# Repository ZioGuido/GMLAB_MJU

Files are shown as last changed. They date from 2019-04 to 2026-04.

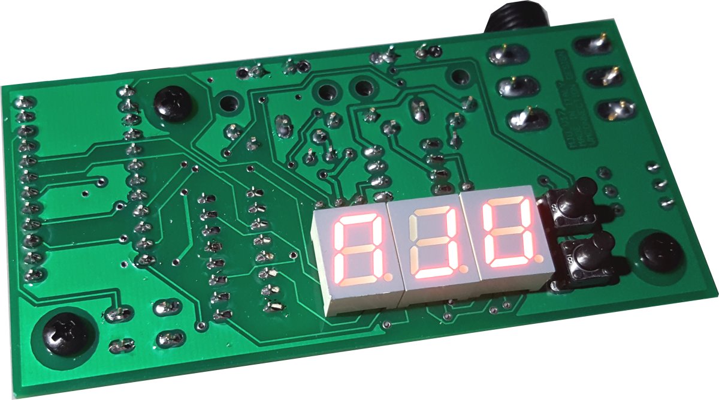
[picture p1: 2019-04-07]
MJU_on.jpg

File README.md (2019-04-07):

# GMLAB_MJU
# MIDI JACK USB

This is an open-source open-hardware D-I-Y Midi event processor and TRS Accessory converter based on Arduino and the Pro-Micro board.
All necessary files are included in this repository. 
Please refer to the included PDF file for details about the assembly and the programming.

Project website: www.gmlab.it

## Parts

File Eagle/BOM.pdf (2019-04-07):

Foglio1

Pagina 1

# MJU

Part | Value | Device | Package | Description
IC1 | | ARDUINO PRO-MICRO
J1 | STEREO JACK | STEREO JACK | STEREO JACK 6.3
LED1 | 7-SEG_SA39-11SRWA | 7-SEG_SA39-11SRWA | SA39-11SRWA | Kingbright 14.2mm (0.56 INCH) SINGLE DIGIT DISPLAY
LED2 | 7-SEG_SA39-11SRWA | 7-SEG_SA39-11SRWA | SA39-11SRWA | Kingbright 14.2mm (0.56 INCH) SINGLE DIGIT DISPLAY
LED3 | 7-SEG_SA39-11SRWA | 7-SEG_SA39-11SRWA | SA39-11SRWA | Kingbright 14.2mm (0.56 INCH) SINGLE DIGIT DISPLAY
MIDI_IN | MAB5SH | MAB5SH | MAB5SH | Female DIN CONNECTOR
MIDI_OUT | MAB5SH | MAB5SH | MAB5SH | Female DIN CONNECTOR
OK1 | 6N137 | 6N137 | DIL08 | MOTOROLA OPTO COUPLER
R1 | 220 | R-EU_0207/7 | 0207/7 | RESISTOR, European symbol
R2 | 100 | R-EU_0207/7 | 0207/7 | RESISTOR, European symbol
R3 | 220 | R-EU_0207/7 | 0207/7 | RESISTOR, European symbol
R4 | 220 | R-EU_0207/7 | 0207/7 | RESISTOR, European symbol
R5 | 100 | R-EU_0207/7 | 0207/7 | RESISTOR, European symbol
R9 | 10K | R-EU_0207/7 | 0207/7 | RESISTOR, European symbol
R10 | 100 | R-EU_0207/7 | 0207/7 | RESISTOR, European symbol
RN1 | 220 | E4R | SIL8 | SIL RESISTOR
RN2 | 220 | E4R | SIL8 | SIL RESISTOR
S1 | b3f-1000 | 10-XX | B3F-10XX | OMRON SWITCH
S2 | b3f-1070 | 10-XX | B3F-10XX | OMRON SWITCH
S3 | b3f-1070 | 10-XX | B3F-10XX | OMRON SWITCH

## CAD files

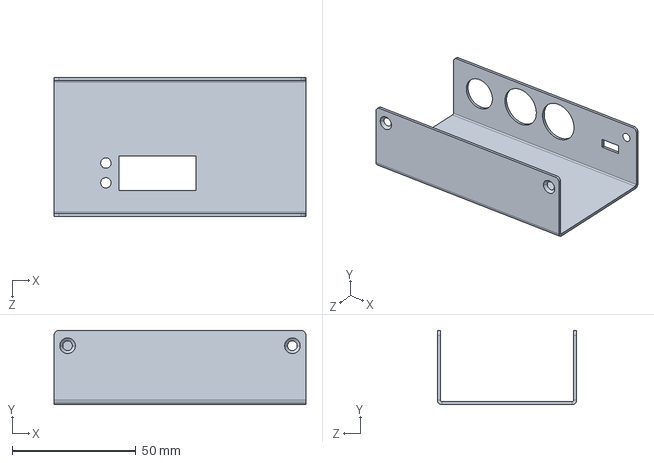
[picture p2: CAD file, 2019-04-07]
3D/Bottom.STEP
102.0 x 30.0 x 56.4 mm

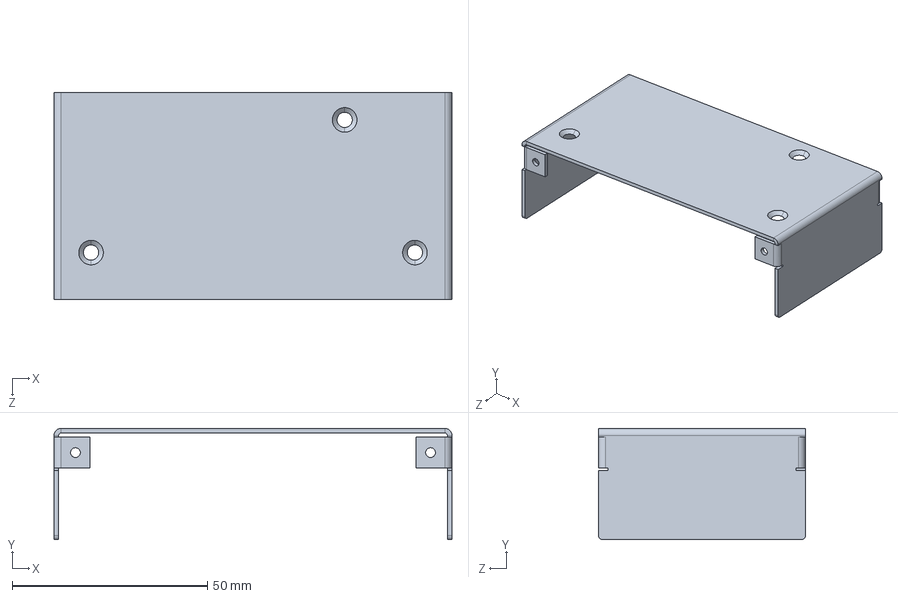
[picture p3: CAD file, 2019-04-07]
3D/Top.STEP
102.0 x 28.5 x 53.0 mm

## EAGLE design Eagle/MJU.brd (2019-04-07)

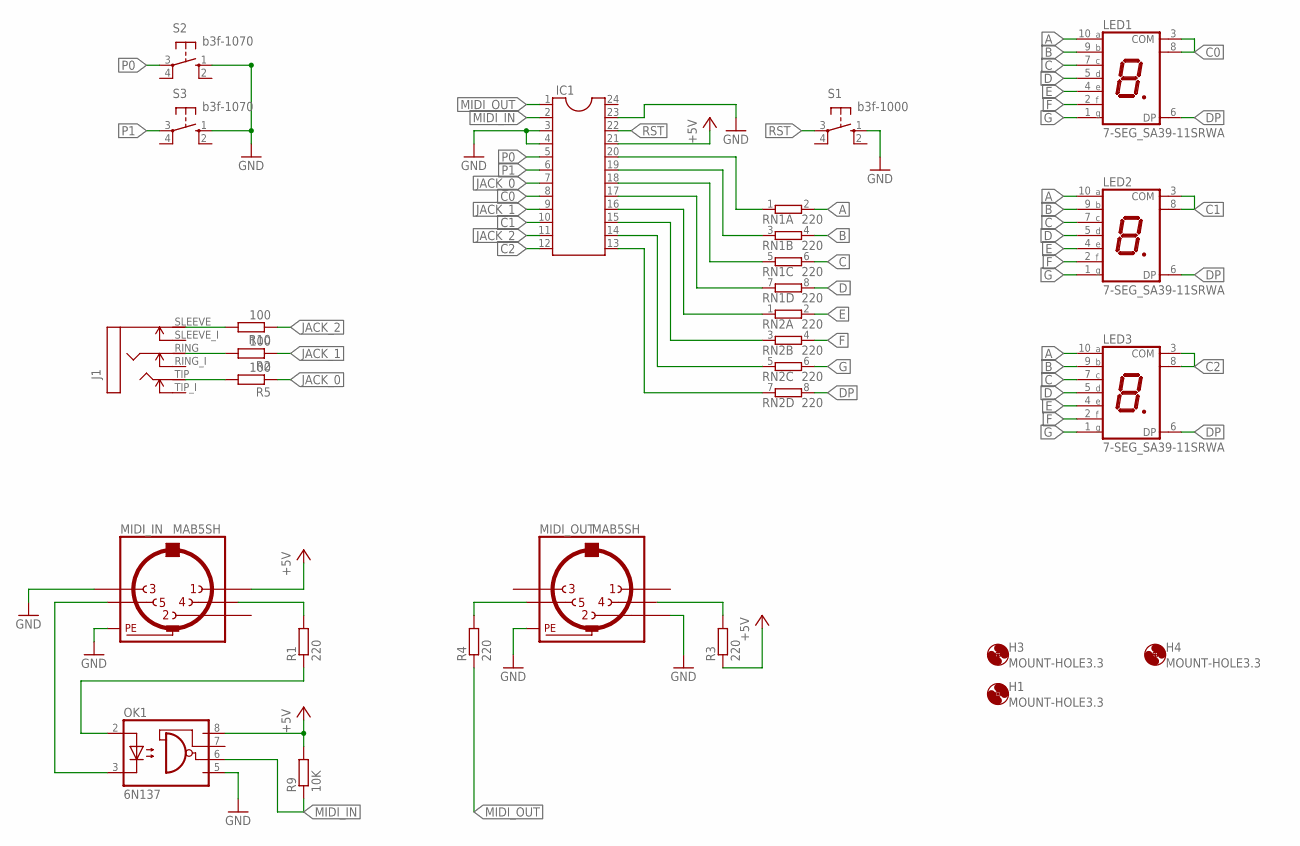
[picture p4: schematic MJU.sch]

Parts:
H1, H3, H4: MOUNT-HOLE3.3; 3,3
IC1: DIL24-6
J1: STEREOSWJACK_ST_TRS_INT; ST_JACK_TRS_INT
LED1, LED2, LED3: 7-SEG_SA39-11SRWA; SA39-11SRWA
MIDI_IN: MAB5SH
MIDI_OUT: MAB5SH
OK1: 6N137; DIL08
R1, R3, R4: 220; 0207/7
R2, R5, R10: 100; 0207/7
R9: 10K; 0207/7
RN1, RN2: 220; SIL8
S1: b3f-1000; B3F-10XX
S2, S3: b3f-1070; B3F-10XX

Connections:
+5V: IC1.21, MIDI_IN.1, OK1.8 (VCC), R3.1, R9.2
A: LED1.10 (A), LED2.10 (A), LED3.10 (A), RN1.2
B: LED1.9 (B), LED2.9 (B), LED3.9 (B), RN1.4 (2)
C: LED1.7 (C), LED2.7 (C), LED3.7 (C), RN1.6 (2)
C0: IC1.8, LED1.3 (COM), LED1.8 (COM)
C1: IC1.10, LED2.3 (COM), LED2.8 (COM)
C2: IC1.12, LED3.3 (COM), LED3.8 (COM)
D: LED1.5 (D), LED2.5 (D), LED3.5 (D), RN1.8 (2)
DP: LED1.6 (DP), LED2.6 (DP), LED3.6 (DP), RN2.8 (2)
E: LED1.4 (E), LED2.4 (E), LED3.4 (E), RN2.2
F: LED1.2 (F), LED2.2 (F), LED3.2 (F), RN2.4 (2)
G: LED1.1 (G), LED2.1 (G), LED3.1 (G), RN2.6 (2)
GND: IC1.3, IC1.4, IC1.23, MIDI_IN.3, MIDI_IN.PE, MIDI_IN.PE@ (PE), MIDI_OUT.2, MIDI_OUT.PE, MIDI_OUT.PE@ (PE), OK1.5 (GND), S1.1 (S), S2.1 (S), S3.1 (S)
JACK_0: IC1.7, R5.1
JACK_1: IC1.9, R2.1
JACK_2: IC1.11, R10.1
MIDI_IN: IC1.2, OK1.6 (VO), R9.1
MIDI_OUT: IC1.1, R4.1
unnamed: J1.SLEEVE (S), R10.2
unnamed: J1.RING (R), R2.2
unnamed: J1.TIP (T), R5.2
unnamed: MIDI_IN.5, OK1.3 (C)
unnamed: OK1.2 (A), R1.1
unnamed: MIDI_IN.4, R1.2
unnamed: MIDI_OUT.5, R4.2
unnamed: MIDI_OUT.4, R3.2
P0: IC1.5, S2.3
P1: IC1.6, S3.3
RST: IC1.22, S1.3
S0: IC1.20, RN1.1
S1: IC1.19, RN1.3 (1)
S2: IC1.18, RN1.5 (1)
S3: IC1.17, RN1.7 (1)
S4: IC1.16, RN2.1
S5: IC1.15, RN2.3 (1)
S6: IC1.14, RN2.5 (1)
S7: IC1.13, RN2.7 (1)

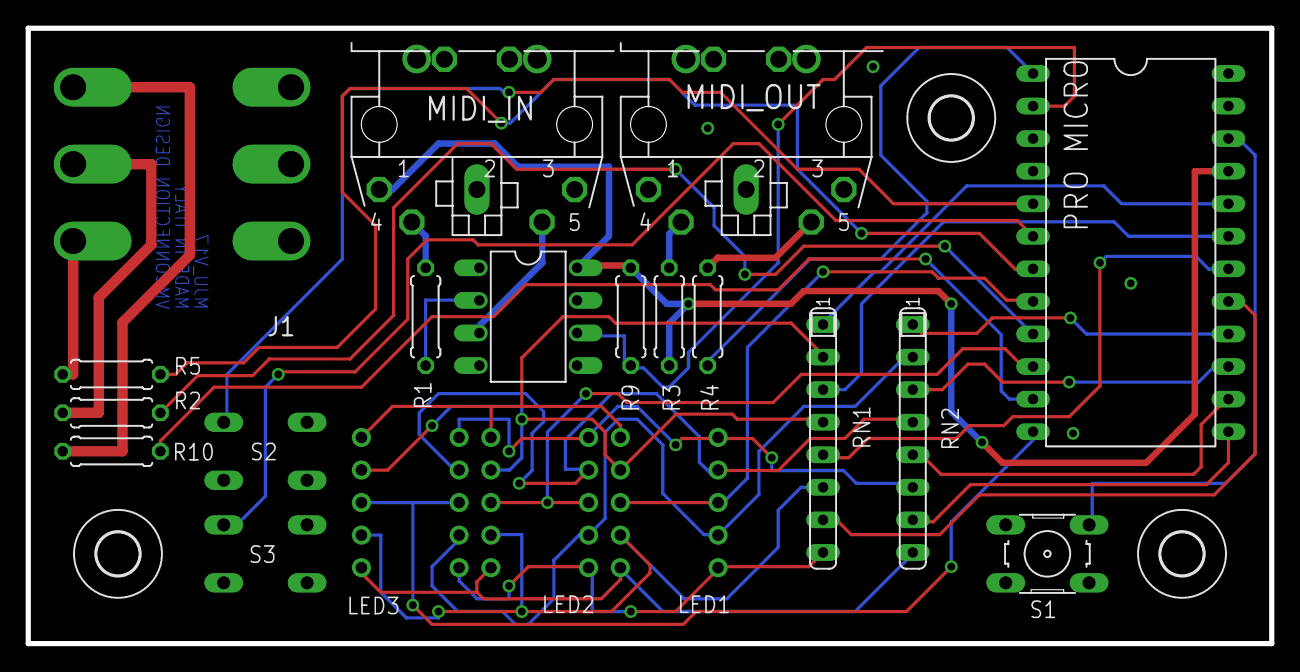
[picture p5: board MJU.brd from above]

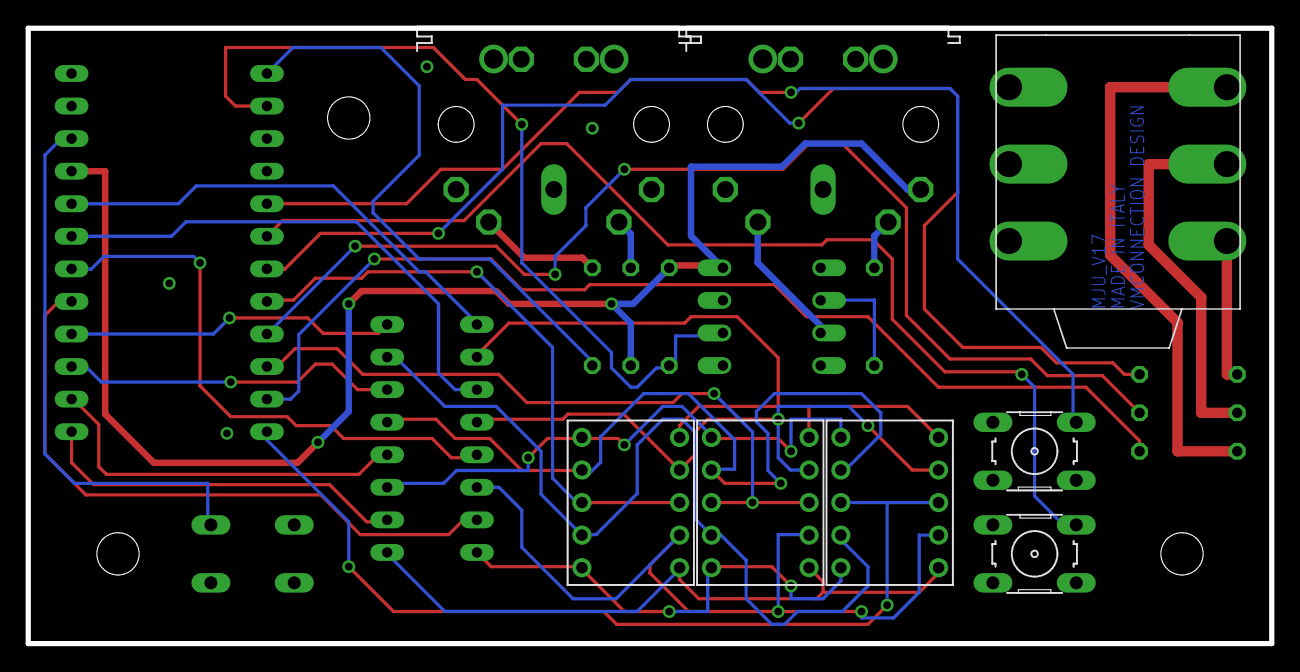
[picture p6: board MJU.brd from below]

Board: 2 copper layers, 97.0 x 48.0 mm, 23 parts (5 on the bottom side), 37 nets.

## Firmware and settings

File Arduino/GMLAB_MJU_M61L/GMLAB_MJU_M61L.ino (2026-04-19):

//////////////////////////////////////////////////////////////////////////////////////////////////////////////////////
// GMLAB MJU - Mojo61L adapter
// This is a modified firmware for the MJU that allows it to transform the data coming 
// from the MOJO61L keyboard into standard MIDI note events
//
// Firmware by Guido Scognamiglio
// Visit: www.gmlab.it
// Last update: April 2026
//

// HOW TO USE:
// Press the upper button to select page (Jack Type, Midi Type, Midi Channel, Midi Number, Range Min, Range Max, Velocity, Transpose, Monitor)
// Press the lower button to select value
// Current status is automatically remembered


//////////////////////////////////////////////////////////////////////////////////////////////////////////////////////
// PIN DEFINITIONS (DO NOT CHANGE!)
#define PIN_SEGMENT_A 21
#define PIN_SEGMENT_B 20
#define PIN_SEGMENT_C 19
#define PIN_SEGMENT_D 18
#define PIN_SEGMENT_E 15
#define PIN_SEGMENT_F 14
#define PIN_SEGMENT_G 16
#define PIN_SEGMENT_P 10
#define PIN_DIGIT0    5
#define PIN_DIGIT1    7
#define PIN_DIGIT2    9
#define PIN_JACK_T    4 // Analog input A6
#define PIN_JACK_R    6 // Analog input A7
#define PIN_JACK_S    8 // Analog input A8
#define PIN_BTN_UP    2
#define PIN_BTN_DN    3


//////////////////////////////////////////////////////////////////////////////////////////////////////////////////////
// Include libraries
#include <EEPROM.h>
#include <MIDI.h>
MIDI_CREATE_DEFAULT_INSTANCE();

#include <USB-MIDI.h>
USBMIDI_CREATE_INSTANCE(0, USB_MIDI);

//////////////////////////////////////////////////////////////////////////////////////////////////////////////////////
// This library creates a timer with millisecond precision
#include "MillisTimer.h"
MillisTimer DisplayTimer; // This is needed for the display
MillisTimer ButtonTimer;  // This is used for debouncing the buttons
MillisTimer PageTimer;    // This is used for changing display pages

//////////////////////////////////////////////////////////////////////////////////////////////////////////////////////
// Variables for the Buttons
int button_pin = -1;
int DebounceTimer, AutorepeatTimer;
#define DEBOUNCE_TIME 100
#define AUTOREPEAT_MAX_TIME  500
#define AUTOREPEAT_MIN_TIME  100
enum Buttons { BTN_UP, BTN_DN };


//////////////////////////////////////////////////////////////////////////////////////////////////////////////////////
// Global variables
char DisplayText[4]; // Holds the text (or number) in the 3 LED digits
int dgt = 0; // Used to cycle through the 3 digits
int MenuPage = -1; // Will be incremented the first time the button is pressed, so will start from page 0
int JackType = 0;
int MidiType = 0;
int MidiChan = 0;
int MidiWhat = 0;
int MidiMin = 0;
int MidiMax = 127;
int PrevMidiValue = -1;
#define MidiType_MAX 2

//////////////////////////////////////////////////////////////////////////////////////////////////////////////////////
// These are used to stabilize the ADC reading
#define DEADBAND    8
int prev_value = DEADBAND;

//////////////////////////////////////////////////////////////////////////////////////////////////////////////////////
// Variables and includes for the Mojo61L scanboard processing
#include "velocity_scale.h"
struct { unsigned char TxChan, NoteNum, TxStatus; } NoteMem[128]; // Structure for the note memory
enum eIntNoteStatus { kStatusNone, kStatusVelOFF, kStatusVelON, kStatusNoteOff };
int Contact2[128];
int MidiTxVelocity;
int Transpose;

enum EEPROM_MemoryLocations
{
	EE_LOC_Skip_0 = 0,
	EE_LOC_JackType,
	EE_LOC_MidiType,
	EE_LOC_MidiChan,
	EE_LOC_MidiWhat,
	EE_LOC_MidiMin,
	EE_LOC_MidiMax,

	EE_LOC_Velocity, // Added for the Mojo scanboard modified firmware
};

// Accessories that can be connected to the TRS input
enum JackTypesEnum
{
	e_Jack_ExpPed_WiperOnTip = 0,
	e_Jack_ExpPed_WiperOnRing,
	e_Jack_HalfMoon_Crumar,
	e_Jack_HalfMoon_Hammond,
	e_Jack_Sustain_Positive,
	e_Jack_Sustain_Negative,

	e_JackType_MAX // used to wrap selection counter
};

//////////////////////////////////////////////////////////////////////////////////////////////////////////////////////
// Display strings
const char MenuPages[][4] = { "TRS", "TYP", "CHN", "NUM", "MIN", "MAX", "VEL", "TSP", "MON" };
const char JackTypes[][4] = { "EP1", "EP2", "HMC", "HMH", "SPP", "SPN" };
const char MidiTypes[][4] = { " CC", " PC", "NOT" }; // Control Change, Program Change, Note Event


//////////////////////////////////////////////////////////////////////////////////////////////////////////////////////
// 7 segment LED display characters
const unsigned char alphabet[] =
{  // bit order: 0 A B C D E F G P
  0b011111100,  // 0  // ASCII CHAR 48
  0b001100000,  // 1
  0b011011010,  // 2
  0b011110010,  // 3
  0b001100110,  // 4
  0b010110110,  // 5
  0b010111110,  // 6
  0b011100000,  // 7
  0b011111110,  // 8
  0b011110110,  // 9

  0b000000010,  // Minus sign -
  0,            //    // UNUSED ASCII CHARS
  0,
  0,
  0,
  0,
  0,

  0b011101110,  // A  // ASCII CHAR 65
  0b000111110,  // B
  0b010011100,  // C
  0b001111010,  // D
  0b010011110,  // E
  0b010001110,  // F
  0b010111100,  // G
  0b000101110,  // H
  0b000100000,  // I
  0b001110000,  // J
  0b000000000,  // K (null)
  0b000011100,  // L
  0b011101100,  // M
  0b000101010,  // N
  0b000111010,  // O
  0b011001110,  // P
  0b011100110,  // Q
  0b000001010,  // R
  0b010110110,  // S
  0b000011110,  // T
  0b001111100,  // U
  0b000111000,  // V
  0b000000000,  // W (null)
  0b001101110,  // X
  0b001110110,  // Y
  0b001001010,  // Z
};

// This function prints a single character on the LED display by turning the segments on or off 
void PrintChar(unsigned char c) // Pass ASCII code
{
	unsigned char chr;
	switch (c)
	{
	case '-': chr = alphabet[10]; break;  // Dash symbol
	case ' ': chr = alphabet[11]; break;  // Whitespace
	default:
		// Our array starts from 0, so shift the ASCII value by -48
		chr = alphabet[c - 48];
	}

	// This display uses common anode, so a segment must be LOW for On and HIGH for Off
	digitalWrite(PIN_SEGMENT_A, !(chr >> 7 & 1));
	digitalWrite(PIN_SEGMENT_B, !(chr >> 6 & 1));
	digitalWrite(PIN_SEGMENT_C, !(chr >> 5 & 1));
	digitalWrite(PIN_SEGMENT_D, !(chr >> 4 & 1));
	digitalWrite(PIN_SEGMENT_E, !(chr >> 3 & 1));
	digitalWrite(PIN_SEGMENT_F, !(chr >> 2 & 1));
	digitalWrite(PIN_SEGMENT_G, !(chr >> 1 & 1));
	digitalWrite(PIN_SEGMENT_P, !(chr & 1));
}

// Called to turn all segments off
void ClearChar()
{
	digitalWrite(PIN_SEGMENT_A, 1);
	digitalWrite(PIN_SEGMENT_B, 1);
	digitalWrite(PIN_SEGMENT_C, 1);
	digitalWrite(PIN_SEGMENT_D, 1);
	digitalWrite(PIN_SEGMENT_E, 1);
	digitalWrite(PIN_SEGMENT_F, 1);
	digitalWrite(PIN_SEGMENT_G, 1);
	digitalWrite(PIN_SEGMENT_P, 1);
}

// Called to set a 3-digit number to be displayed (0 to 999)
void DisplayNumber(unsigned char num)
{
	unsigned char h = num / 100;                // Hundreds (left digit)
	unsigned char t = (num - h * 100) / 10;     // Tens     (middle digit)
	unsigned char u = num - h * 100 - t * 10;   // Units    (right digit)

	// Add 48 to match ASCII value
	// These conditional statements replace the leading zeroes with whitespaces
	DisplayText[0] = h > 0 ? 48 + h : ' ';
	DisplayText[1] = t > 0 ? 48 + t : (h > 0 ? 48 + t : ' ');
	DisplayText[2] = 48 + u;
}

// This function is called by the timer to cycle through the display digits
void DisplayLoop()
{
	// 1. Call this at each interaction before turning the segments off in order to reduce the "leakage"
	ClearChar();

	// 2. Shift to next digit
	if (++dgt > 2) dgt = 0;

	// 3. Toggle digits (turn on the current digit and turn off the other two)
	digitalWrite(PIN_DIGIT0, dgt == 0);
	digitalWrite(PIN_DIGIT1, dgt == 1);
	digitalWrite(PIN_DIGIT2, dgt == 2);

	// 4. Print the requested character
	PrintChar(DisplayText[dgt]);
}

// Called to cycle through display pages
void BrowsePage()
{
	if (++MenuPage > 6) MenuPage = 0; // Added 2 more pages for the Mojo Scanboard modified firmware
	memcpy(DisplayText, MenuPages[MenuPage], 3);

	// Start a timer of 1 second, the page value will be shown when this expires
	PageTimer.reset();
	PageTimer.start();
}

// Called to set a value to the current page
void SetPageValue()
{
	// Change value if the button has been pushed
	if (button_pin == BTN_DN)
	{
		switch (MenuPage)
		{
		case 0: // Jack Type
			if (++JackType >= e_JackType_MAX) JackType = 0;
			EEPROM.write(EE_LOC_JackType, JackType);
			ConfigureTRS();
			break;

		case 1: // Midi Type
			if (++MidiType > MidiType_MAX) MidiType = 0;
			EEPROM.write(EE_LOC_MidiType, MidiType);
			break;

		case 2: // Midi Channel
			if (++MidiChan > 15) MidiChan = 0;
			EEPROM.write(EE_LOC_MidiChan, MidiChan);
			break;

		case 3: // Midi What
			if (++MidiWhat > 127) MidiWhat = 0;
			EEPROM.write(EE_LOC_MidiWhat, MidiWhat);
			break;

		case 4: // Range Min
			if (++MidiMin > 127) MidiMin = 0;
			EEPROM.update(EE_LOC_MidiMin, MidiMin);
			break;

		case 5: // Range Max
			if (++MidiMax > 127) MidiMax = 0;
			EEPROM.update(EE_LOC_MidiMax, MidiMax);
			break;

		case 6: // Velocity on or off
			if (++MidiTxVelocity > 1) MidiTxVelocity = 0;
			EEPROM.write(EE_LOC_Velocity, MidiTxVelocity);
			break;

		case 7: // Transpose (not stored into EEPROM)
			if (++Transpose > 12) Transpose = -12;
			break;
		}
	}

	// Display current value
	switch (MenuPage)
	{
	case 0: // Jack Type
		memcpy(DisplayText, JackTypes[JackType], 3);
		break;

	case 1: // Midi Type
		memcpy(DisplayText, MidiTypes[MidiType], 3);
		break;

	case 2: // Midi Channel
		DisplayNumber(MidiChan + 1);
		break;

	case 3: // Midi What
		DisplayNumber(MidiWhat);
		break;

	case 4: // Midi Min
		DisplayNumber(MidiMin);
		break;

	case 5: // Midi Max
		DisplayNumber(MidiMax);
		break;

	case 6: // Velocity
		memcpy(DisplayText, MidiTxVelocity > 0 ? " ON" : "OFF", 3);
		break;

	case 7: // Transpose
		// Ouch! This is though!... In order to display this correctly, we must show this as a text
		sprintf(DisplayText, "%s%2d", Transpose < 0 ? "-" : " ", abs(Transpose));
		break;
	}
}

// Called whenever the TRS Type is changed, sets the I/O ports for the desired type
void ConfigureTRS()
{
	switch (JackType)
	{
	case e_Jack_ExpPed_WiperOnTip:
		pinMode(PIN_JACK_T, INPUT);
		pinMode(PIN_JACK_R, OUTPUT);  digitalWrite(PIN_JACK_R, HIGH);   // Set Ring as VCC
		pinMode(PIN_JACK_S, OUTPUT);  digitalWrite(PIN_JACK_S, LOW);    // Set Sleeve as GND
		break;

	case e_Jack_ExpPed_WiperOnRing:
		pinMode(PIN_JACK_T, OUTPUT);  digitalWrite(PIN_JACK_T, HIGH);   // Set Tip as VCC
		pinMode(PIN_JACK_R, INPUT);
		pinMode(PIN_JACK_S, OUTPUT);  digitalWrite(PIN_JACK_S, LOW);    // Set Sleeve as GND
		break;

	case e_Jack_HalfMoon_Crumar:
		pinMode(PIN_JACK_T, INPUT_PULLUP);
		pinMode(PIN_JACK_R, OUTPUT);  digitalWrite(PIN_JACK_R, LOW);   // Set Ring as GND
		pinMode(PIN_JACK_S, INPUT_PULLUP);
		break;

	case e_Jack_HalfMoon_Hammond:
		pinMode(PIN_JACK_T, INPUT_PULLUP);
		pinMode(PIN_JACK_R, INPUT_PULLUP);
		pinMode(PIN_JACK_S, OUTPUT);  digitalWrite(PIN_JACK_S, LOW);    // Set Sleeve as GND
		break;

	case e_Jack_Sustain_Positive:
	case e_Jack_Sustain_Negative:
		pinMode(PIN_JACK_T, INPUT_PULLUP);
		pinMode(PIN_JACK_R, OUTPUT);  digitalWrite(PIN_JACK_R, LOW);    // Set Ring as GND
		pinMode(PIN_JACK_S, OUTPUT);  digitalWrite(PIN_JACK_S, LOW);    // Set Sleeve as GND
		break;
	}
}

// Reads an Analog Input and applies the "dead band" filter
int ReadADC(int ADC_PIN)
{
	// Get the 10-bit value from the ADC
	int value = analogRead(ADC_PIN);

	// Get difference between current and previous value
	int diff = abs(value - prev_value);

	// Exit this function if the new value is within the deadband
	if (diff <= DEADBAND) return;

	// Store new value
	prev_value = value;

	// Get the 7 bit Midi value by shifting the bits to the right by 3 positions
	return value >> 3;
}

// Called to read the TRS inputs and generate the MIDI event whenever the input has changed status
void ReadTRS()
{
	int MidiValue;

	switch (JackType)
	{
		///////////////////////////////////////////////////
	case e_Jack_ExpPed_WiperOnTip:
		MidiValue = ReadADC(A6);
		break;

		///////////////////////////////////////////////////
	case e_Jack_ExpPed_WiperOnRing:
		MidiValue = ReadADC(A7);
		break;

		///////////////////////////////////////////////////
	case e_Jack_HalfMoon_Crumar:
		if (digitalRead(PIN_JACK_T) == LOW)
			MidiValue = 127;  // Fast
		else
			if (digitalRead(PIN_JACK_S) == LOW)
				MidiValue = 0;    // Slow
			else
				MidiValue = 64;   // Stop
		break;

		///////////////////////////////////////////////////
	case e_Jack_HalfMoon_Hammond:
		if (digitalRead(PIN_JACK_T) == LOW)
			MidiValue = 0;    // Slow
		else
			if (digitalRead(PIN_JACK_R) == LOW)
				MidiValue = 127;  // Fast
			else
				MidiValue = 64;   // Stop
		break;

		///////////////////////////////////////////////////
	case e_Jack_Sustain_Positive:
		MidiValue = digitalRead(PIN_JACK_T) ? 127 : 0;
		break;

		///////////////////////////////////////////////////
	case e_Jack_Sustain_Negative:
		MidiValue = digitalRead(PIN_JACK_T) ? 0 : 127;
		break;
	}

	// Send only if the state has changed
	if (PrevMidiValue != MidiValue)
		SendMidiMessage(MidiValue);

	// Remember previous state
	PrevMidiValue = MidiValue;
}

// Called after a button has been debounced
void ButtonUpdate()
{
	switch (button_pin)
	{
	case BTN_UP:
		BrowsePage();
		break;

	case BTN_DN:
		SetPageValue();
		break;
	}

	// Accelerate auto-repeat
	if (AutorepeatTimer > AUTOREPEAT_MIN_TIME)
		AutorepeatTimer -= 100;
}

// Called every 1 millisecond to check for button states and apply the debounce timer
void CheckButtons()
{
	// Check if either upper or lower button has been depressed
	if (digitalRead(PIN_BTN_UP) == LOW)
	{
		button_pin = BTN_UP;
		++DebounceTimer;
	}
	else
	if (digitalRead(PIN_BTN_DN) == LOW)
	{
		button_pin = BTN_DN;
		++DebounceTimer;
	}
	else
	{
		// If no buttons are pushed, reset the debounce timer
		button_pin = -1;
		DebounceTimer = 0;
		AutorepeatTimer = AUTOREPEAT_MAX_TIME;
		return;
	}

	// Check debounce
	if (DebounceTimer == DEBOUNCE_TIME) ButtonUpdate();
	if (DebounceTimer >= AutorepeatTimer) DebounceTimer = 0; // Enable auto-repeat
}

// Called to generate and send the desired MIDI event
void SendMidiMessage(int MidiValue)
{
	switch (MidiType)
	{
	case 0: // Send Control Change
		MIDI.sendControlChange(MidiWhat, MidiValue, MidiChan + 1);
		USB_MIDI.sendControlChange(MidiWhat, MidiValue, MidiChan + 1);
		break;

	case 1: // Send Program Change
		MIDI.sendProgramChange(MidiValue, MidiChan + 1);
		USB_MIDI.sendProgramChange(MidiValue, MidiChan + 1);
		break;

	case 2: // Send Note On
		MIDI.sendNoteOn(MidiWhat, MidiValue, MidiChan + 1);
		USB_MIDI.sendNoteOn(MidiWhat, MidiValue, MidiChan + 1);
		break;
	}

	// Monitor MidiValue
	if (MenuPage == 8)
		DisplayNumber(MidiValue);
}

// This function is called only by the scanboard function to send note on or off messages
void SendNoteMessage(int byte1, int note, int velocity)
{
	int status = byte1 & 0xF0;
	int chn = byte1 & 0x0F;
	switch (status)
	{
	case 0x90: // Note ON
		MIDI.sendNoteOn(note, velocity, chn + 1);
		USB_MIDI.sendNoteOn(note, velocity, chn + 1);
		break;

	case 0x80: // Note OFF
		MIDI.sendNoteOff(note, velocity, chn + 1);
		USB_MIDI.sendNoteOff(note, velocity, chn + 1);
		break;
	}
}

/*  Here is a little secret: the scan board of the Mojo (also used in all Mojo models and in the GSi DMC-122)
 *  generates plain MIDI data, using distinct messages for each of the two bubble contacts and for each event
 *  when a contact is closed or opened. Rather than generating note events, it uses the PolyAftertouch event (0xA0)
 *  which is a 3-byte event just like note events. The main CPU then translates these messages in note events by
 *  applying velocity or not, according to the instrument settings, and deciding whether the note on event must be
 *  sent at the first contact (for better organ response) or at the second contact (needed for calculating the
 *  velocity information). This function is an excerpt of what the Mojo's main CPU does with the data coming
 *  from the scan board.
 *  This function also applies a two velocity curves, one only for compensating the lever action of the black
 *  keys, which are shorter and have the finger apply the force closer to the fulcrum; the second curve is
 *  applied on top of all for a better response with the TP-8o keyboard.
 *  One further feature is the use of the "note memory", which stores each note's channel and number when the
 *  note-on event is generated, and uses them when the note-off must be generated, so to avoid orphan note-on events
 *  in case the channel or the transposition is changed after a note is played and before it's released.
*/
void ProcessMojoScanboard(int chan, int note, int velocity)
{
	int Status = kStatusNone;

	// * ******************************************************* * /
	// Messages coming from the SCAN MATRIX v2.4 (MojoScan3):
	// KEY DOWN (contact closed):
	//    First contact   = 0xA0 0xA1 with value 127;
	//    Second contact  = 0xA2 0xA3 with velocity;
	//
	// KEY UP (contact opened):
	//    Second contact  = 0xA4 0xA5 with value 0
	//    First contact   = 0xA6 0xA7 with value 0

	// * ******************************************************* * /
	// FIRST THING: calculate note-off velocity based on the time
	// interval between second and first contact being opened

	switch (chan)
	{
		// if second contact is opened
	case 4:
		Contact2[note] = millis();
		return;

		// if first contact is opened
	case 6:
		if (Contact2[note] > 0) // check that a value was stored into the array for this note
		{
			int time_diff = millis() - Contact2[note];  // calc the time difference
			if (time_diff > 127) time_diff = 127;       // trim to 127
			velocity = 127 - time_diff;                 // assign to velocity byte
			Contact2[note] = 0;                         // reset array
			velocity = VelocityScale[velocity];         // Apply velocity scaling
		}
		else velocity = 0;                          // use velocity = 0 if the second contact was never reached

		// Set Status
		Status = kStatusNoteOff;
		break;

		// First contact
	case 0:
		Status = kStatusVelOFF;
		break;

		// Second contact
	case 2:
		// Find black keys and apply velocity compensation
		for (int p = 0; p < 25; p++) { if (note == BlackKey_note_num[p]) { velocity = BlackKeyVelocity[velocity]; break; } }

		// Apply velocity scaling
		velocity = VelocityScale[velocity];

		// Set Status
		Status = kStatusVelON;
		break;
	}


	// Generate outgoing messages using note memory for NOTE ON and NOTE OFF
	switch (Status)
	{
	case kStatusVelOFF: // First contact, no velocity
		// Store note and channel
		NoteMem[note].TxChan = MidiChan;
		NoteMem[note].NoteNum = note + Transpose;

		// Send if velocity feature is OFF
		if (MidiTxVelocity == 0)
		{
			SendNoteMessage(0x90 | NoteMem[note].TxChan, NoteMem[note].NoteNum, velocity);
			NoteMem[note].TxStatus = 1;
		}
		break;

	case kStatusVelON: // Second contact, velocity
		// Send if velocity feature is ON // Added 18-Mar-2024: Only if a Note-On message wasn't already sent!
		if (MidiTxVelocity == 1 && NoteMem[note].TxStatus == 0)
		{
			SendNoteMessage(0x90 | NoteMem[note].TxChan, NoteMem[note].NoteNum, velocity);
			NoteMem[note].TxStatus = 1;
		}
		break;

	case kStatusNoteOff:
		// Send note off event using note memory
		if (NoteMem[note].TxStatus)
		{
			SendNoteMessage(0x80 | NoteMem[note].TxChan, NoteMem[note].NoteNum, velocity);
			NoteMem[note].TxStatus = 0;
		}
		break;
	}
}
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
void loop()
{
	// Process incoming Midi messages
	if (MIDI.read())
	{
		// Process only PolyAftertouch messages (see comments above)
		if (MIDI.getType() == 0xA0)
			// NOTE to self: remember that this MIDI library uses actual channel numbers 1~16 !!!
			ProcessMojoScanboard(MIDI.getChannel() - 1, MIDI.getData1(), MIDI.getData2());
	}

	USB_MIDI.read();

	// Read TRS input
	ReadTRS();

	// Run Timers
	DisplayTimer.run();
	PageTimer.run();
	ButtonTimer.run();
}

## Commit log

2022-12-13 Fixed bug with transpose setting
    [GMLAB_MJU_M61L.ino]
2024-03-18 Fix for possible hung notes with velocity on
    Added lock to avoid double note-on events with velocity on
    [GMLAB_MJU_M61L.ino]
